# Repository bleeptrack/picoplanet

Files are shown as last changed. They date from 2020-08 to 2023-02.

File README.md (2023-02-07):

# PicoPlanet
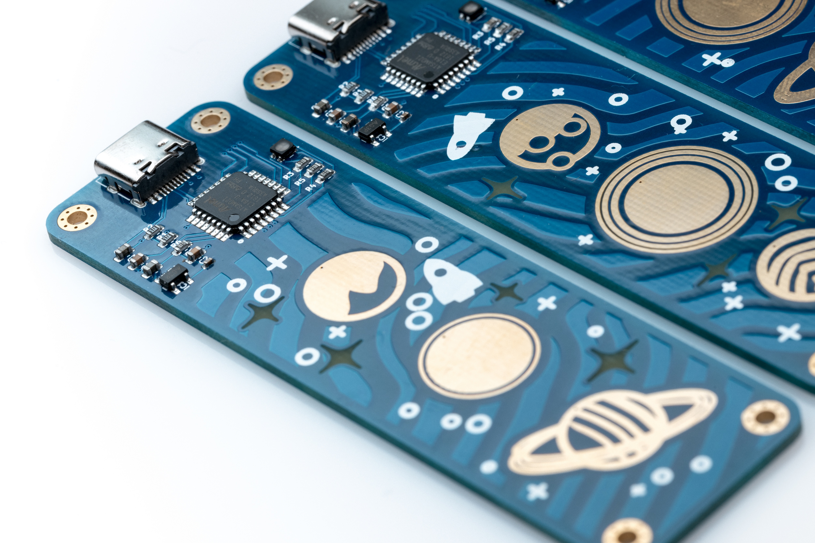
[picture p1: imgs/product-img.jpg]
Product Image

PicoPlanet is a series of procedurally designed PCBs.  
Available here: [Tindie](https://www.tindie.com/products/bleeptrack/picoplanet/)  
More information about the design process: link coming soon    

### Features:

- Dimensions: 27.0 x 89.2 mm

- SAMD21
- USB-C
- 3 capacitive touch buttons (planets)
- 1 RGB LED
- 4 additional pins on the backside with 3.3V and 5V

### Pinout
#### Front
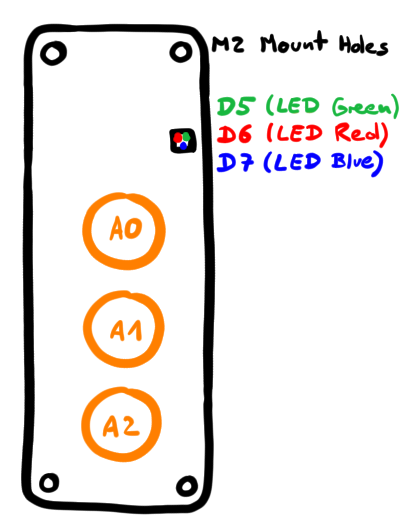
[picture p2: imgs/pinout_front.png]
Pinout Front

#### Back
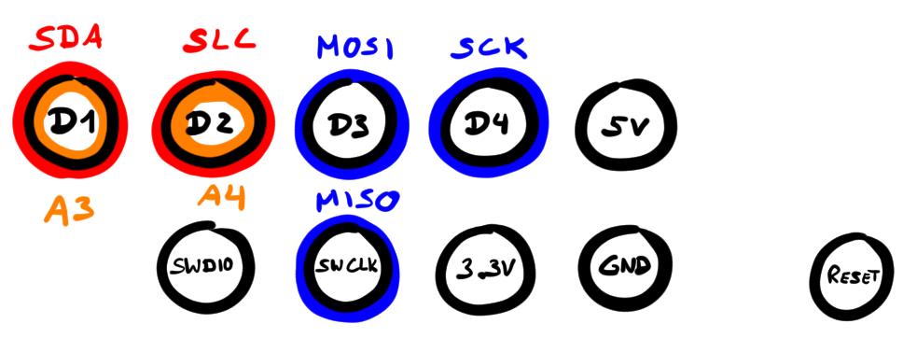
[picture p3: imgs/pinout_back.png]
Pinout Back


### Usage

Important: because the PCBs are procedurally generated, the threshold values for the capacitive touch buttons might need to be adjusted by you.

#### Circuit Python (recommended)

- Download Circuit Python from [circuitpython.org](https://circuitpython.org/board/picoplanet/)
- Connect your PicoPlanet to your PC. A drive called PLANETBOOT should appear.
- Place the firmware on the PLANETBOOT drive and wait for a moment. PLANETBOOT will dismount and a new drive called CIRCUITPY will appear. 
- More information on Circuit Python can be found here: [CPY getting started](https://learn.adafruit.com/welcome-to-circuitpython)
- In case you want to update your Circuit Python Version, you need to bring your board back to bootloader mode. This can be done by connecting a wire to the GND pin on the backside and double tap the RESET pad with the other end of the wire. The PLANETBOOT drive should appear now and you can place the updated firmware in the drive. See [example video](https://youtu.be/1Hi12uxtpS8). 

#### Arduino
- In your Arduino IDE, unter File > Preferences add `https://boards.bleeptrack.de/package_bleeptrack_index.json` to "Additional Boards Manager URLs"
- Open your Board Manager. Search for "bleeptrack boards" and install them.
- Choose bleeptrack boards > PicoPlanet in your Board selection
- Compile and upload :)
- If Arduino does not detect your PicoPlanet board, bring your board into bootloader mode by connecting a wire to the GND pin on the backside and double tap the RESET pad with the other end of the wire. The PLANETBOOT drive should appear now and the Arduino IDE will recognize the board again. See [example video](https://youtu.be/1Hi12uxtpS8). 
- The LED RGB Pins can directly be accessed by `LED_R`, `LED_G`, `LED_B`

#### Troubleshooting
- `bossac` not found when compiling Arduino Sketch: reinstall `bleeptrack-boards` package or install another package that contains bossac like `Arduino SAMD Boards (32-bits ARM Cortex-M0+)`

## Generator

You can play with the generator yourself. Run `npm install` in the `generator` folder to download the dependencies. Open `index.html` and reload the page to generate a new image. You have two options to save: `Perfect Purple` gives a SVG that is compatible with svg2shenzen and is made for typical PCBs (like the Oshpark's Perfect Purple). You can also choose `After Dark` which is specifically made for Oshpark's After Dark with a black base plate and a clear solder mask.

The generated images are currently not suitable to use them directly for pen plotters (and in the vector format also not for laser cutters). You might need to adjust them to your needs.

You are free to use the code and the generated images in any non-commercial way. 

## Accessories
- A case by [tinyledmatrix](https://twitter.com/tinyledmatrix) can be found in this repo in the ``frameCase`` folder
- Another case by Kartoffel is on Thingiverse: [Bumpercase](https://www.thingiverse.com/thing:4583005)

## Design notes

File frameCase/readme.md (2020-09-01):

Little 3D-printed case/frame for PicoPlanet by Alex (@tinyledmatrix)

Included Files:
STL
3MF with used settings in PrusaSlicer

License:
All files in this directory are
[CC-NC-SA-4.0](https://creativecommons.org/licenses/by-nc-sa/4.0/)

How does it look?
See [this](https://twitter.com/tinyledmatrix/status/1300056528297373696) Tweet

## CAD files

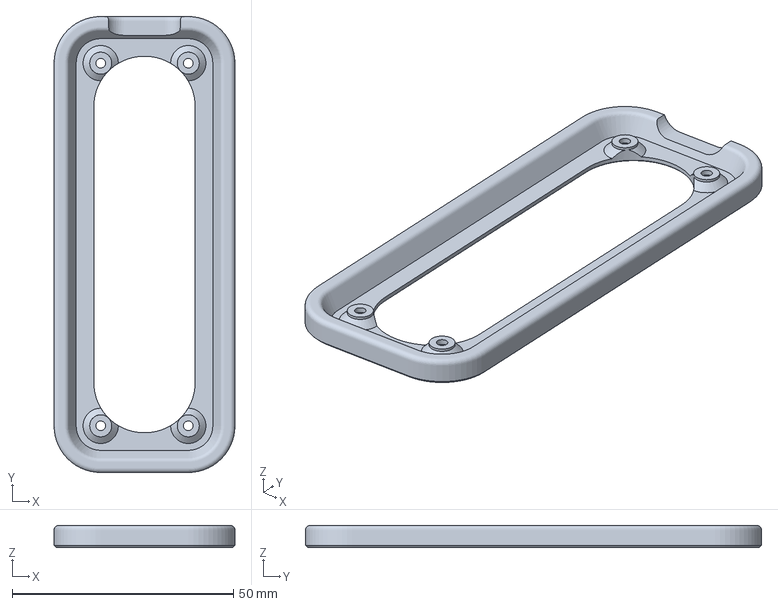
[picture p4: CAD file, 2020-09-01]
frameCase/picoPlanetFrame.3mf
40.9 x 103.2 x 5.00 mm

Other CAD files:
frameCase/picoPlanetFrame.stl

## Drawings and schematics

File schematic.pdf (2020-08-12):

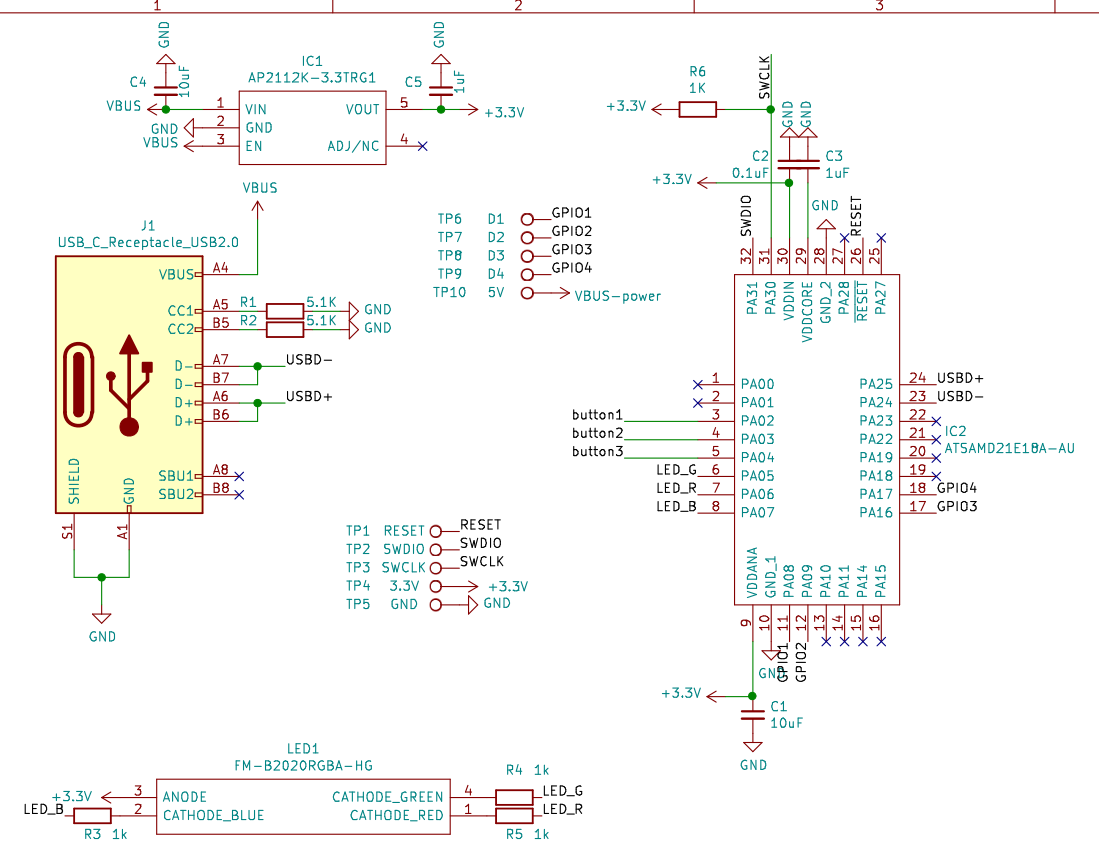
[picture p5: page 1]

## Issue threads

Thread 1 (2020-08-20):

Arduino: Upload Error: bossac not found

HayWo, 2020-08-20:
Uploading a sketch to the PicoPlanet fails, because a tool called `bossac` was not found.

### How to fix this
Install the Arduino Board Manager called `Arduino SAMD Boards (32-bits ARM Cortex-M0+)`

bleeptrack, 2020-08-20:
Hey HayWo! Oh well, that's weird! I tested on a fresh arduino install and did not encounter this problem. bossac is declared in the toolDependencies and should be installed with the bleeptrack-board package. Though seems it did not work for you.
I'll add your workaround to a Troubleshooting section.
Would you mind telling me what Arduino IDE version and OS you are running? Thanks!

HayWo, 2020-08-20:
I'm using Arduino IDE 1.8.13 on Arch Linux. Maybe I just have a messed up installation of the IDE.

Closed 2020-08-20.

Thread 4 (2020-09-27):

Updating CircuitPython version

bergold, 2020-09-27:
Is there an easy way to get into the bootloader again? So I can drag-n-drop a new uf2 file.

bleeptrack, 2020-09-27:
Hey bergold! Yes there is :)
To bring your board into bootloader mode, connect a wire to the GND pin on the backside and double tap the RESET pad with the other end of the wire. The PLANETBOOT drive should appear now.

I currently only wrote about this in the Arduino section. I'll update the readme file in the Circuit Python section, too :)

bergold, 2020-09-27:
Thanks for the quick reply! :)

Closed 2020-09-27.

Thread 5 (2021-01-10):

PlatformIO support / example

xsrf, 2021-01-10:
Hey,
do you have any experience with support for PlatformIO? PlatformIO requires a board definition and won't work out of the box, even if some supported boards already use the `SAMD21E18A`.
I kind of made it work by creating my own board variant based on the Adafruit Trinket M0 but I have no clue if it was done correctly. I may add a PR if I'm confident enough, but I'd be thankful for any additional advice ;)

xsrf, 2021-01-10:
Okay, I came up with a working example: https://github.com/xsrf/picoplanet/tree/platformio/example/platformio
I have slightly different pin definitions in [variant.cpp](https://github.com/xsrf/picoplanet/blob/platformio/example/platformio/variants/bleeptrack_picoplanet/variant.cpp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) and [variant.h](https://github.com/xsrf/picoplanet/blob/platformio/example/platformio/variants/bleeptrack_picoplanet/variant.h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) though.

Since I used the Trinket M0 as template, I kept `Serial1` using `SERCOM0` and used `SERCOM2` for `I2C`. Since `SERCOM0` and `SERCOM2` share the same pins they can be used interchangeably but of course both cannot be used at the same time.
However, this allows for `Serial1` with `TX`/`RX` on `D1`/`D2`.

Also, I think you got the PWM channels wrong for the LEDs.
Yours is
```cpp
  { PORTA,  5, PIO_SERCOM, (PIN_ATTR_DIGITAL|PIN_ATTR_PWM|PIN_ATTR_TIMER), ADC_Channel5, PWM1_CH0, TCC0_CH1, EXTERNAL_INT_5 },
  { PORTA,  6, PIO_SERCOM, (PIN_ATTR_DIGITAL|PIN_ATTR_PWM|PIN_ATTR_TIMER), ADC_Channel6, PWM1_CH1, TCC1_CH0, EXTERNAL_INT_6 },
  { PORTA,  7, PIO_SERCOM, (PIN_ATTR_DIGITAL|PIN_ATTR_PWM|PIN_ATTR_TIMER), ADC_Channel7, PWM1_CH2, TCC1_CH1, EXTERNAL_INT_7 },
```
But I think it should be
```cpp
  { PORTA,  5, PIO_DIGITAL, (PIN_ATTR_DIGITAL|PIN_ATTR_ANALOG|PIN_ATTR_PWM|PIN_ATTR_TIMER), ADC_Channel5, PWM0_CH1, TCC0_CH1, EXTERNAL_INT_5 },
  { PORTA,  6, PIO_DIGITAL, (PIN_ATTR_DIGITAL|PIN_ATTR_ANALOG|PIN_ATTR_PWM|PIN_ATTR_TIMER), ADC_Channel6, PWM1_CH0, TCC1_CH0, EXTERNAL_INT_6 },
  { PORTA,  7, PIO_DIGITAL, (PIN_ATTR_DIGITAL|PIN_ATTR_ANALOG|PIN_ATTR_PWM|PIN_ATTR_TIMER), ADC_Channel7, PWM1_CH1, TCC1_CH1, EXTERNAL_INT_7 },
```
At least `analogWrite()` works fine with my definition for all three LEDs (see examle code).
Does `analogWrite()` work for you in the ArduinoIDE for all three LEDs?

bleeptrack, 2021-01-10:
Hey, thanks so much for your help (and sorry for my late reply)! I did a quick test and you are right: PWM is not working with my definition. Thanks a lot for checking - I'm really new into defining own board definitions for Arduino and it seems I messed up here. I'll test your version tomorrow and change it so it get's updated for the Arduino IDE.
Also thanks a lot for making PicoPlanets compatible with platformIO! I never used it myself, so feel free to make a PR :)

xsrf, 2021-01-11:
Well, this stuff is really not well documented... PlatformIO and Arduino IDE share kind of the same board definition schemes, but I didn't know that when I started yesterday ;) This is why I first used the Adafruit Trinket M0 as template, because it is one of the Boards already supported by Platform IO that uses the same MCU ( https://platformio.org/boards?filter%5Bmcu%5D=SAMD21E18A ).
It was after that, that I learned you had to do kind of the same and only then I had a first look a your arduino board files.

I think that's kind of fortunate at the end, because if I had found your board files first, I'd just copied and used them and maybe wouldn't have found the issues.

I still have to adapt mine a little... e.g. I've chosen the blue LED to be the `LED_BUILTIN` one, you chose red ;)

Also, I used `#define LED_R`, you used `static const uint8_t LED_R` ... Do you know any cases where this makes a difference? I've also seen the Trinket one using some `const` as well, but it's inconsistent anyways. I guess it matters when you use it by reference 🤔

Regarding PlatformIO support: So far, my example comes together with the boards definition, since your board is not yet officially supported. But this makes the project kinda bulky.
I don't know (yet) what the official way is to get a board submitted into the PlatformIO registry, but maybe we could have a look.
At least, the example project should contain everything that is needed...

xsrf, 2021-01-11:
Oh btw., just in case you'll try it out, the HID example doesn't work for me (in my platformio example). I do get a HID Keyboard in the device manager but the Media-Keys just do nothing... Never used HID so far and haven't looked into that any further for now.

bleeptrack, 2021-01-11:
I did a quick check and with your pin definition, PWN works now \o/

> I think that's kind of fortunate at the end, because if I had found your board files first, I'd just copied and used them and maybe wouldn't have found the issues.

Tbh I'm very happy that you found these issues! I had quite some trouble getting the definitions to work, so it's great that another person now checks them :) Sorry for your extra work though!

> Also, I used `#define LED_R`, you used `static const uint8_t LED_R` ... Do you know any cases where this makes a difference? I've also seen the Trinket one using some `const` as well, but it's inconsistent anyways. I guess it matters when you use it by reference thinking

Not really sure what the difference is. I took most of my definition from another board, but I#m not sure which one it was.

> Regarding PlatformIO support: So far, my example comes together with the boards definition, since your board is not yet officially supported. But this makes the project kinda bulky.
> I don't know (yet) what the official way is to get a board submitted into the PlatformIO registry, but maybe we could have a look.
> At least, the example project should contain everything that is needed...

From what I found they want a feature request: https://platformio.org/boards which would just be a issue in the github repo. I guess if we would provide all necessary information, the board should be quick to add. From the code base I think that we can not just add it via PR. At least I did not find the spot where the variant files are.

> Oh btw., just in case you'll try it out, the HID example doesn't work for me (in my platformio example). I do get a HID Keyboard in the device manager but the Media-Keys just do nothing... Never used HID so far and haven't looked into that any further for now.

Hum, it might be because the HID library I use is not the standard one. I choose the one from NicoHood because it has MediaKeys implemented and the standard one does not :(

I'm a bit occupied in the next few days, but after that I will update the Arduino IDE definitions with your changes :) Again thank you very much for your help!

xsrf, 2021-01-24:
> Hum, it might be because the HID library I use is not the standard one. I choose the one from NicoHood because it has MediaKeys implemented and the standard one does not :(

I've used the [correct library](https://github.com/xsrf/picoplanet/blob/platformio/example/platformio/platformio.ini#L20), but the media keys don't work on my windows pc. However, with the picoplanet connected to my android phone, they just work fine. Regular keys also work on windows. Not sure what the deal is, but it proofs that HID in general works fine.

I've now just created a PR ;)

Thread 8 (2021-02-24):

I added more types of keyboard input examples to the circuitpython example

SHMAUS-Carter, 2021-02-24:
#7 circuitpython keyboard_text_example
I'm still relatively new to pushes and pulls hopefully I did it correctly.

Closed 2021-02-24.

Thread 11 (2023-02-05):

Proposal: Add information how to update Circuit Python version

Isolator70, 2023-02-05:
Some time ago I installed Circuit Python version version 6.3.0 on my Picoplanet board and I'd like to update to the latest and greatest version 7.3.3 now.
I suspect that it can be done by means of the reset contact, but I am not really sure if this right.

--> Would you be so kind to add this information?

bleeptrack, 2023-02-07:
Hey Isolator70! That is a great suggestion, thank you a lot! With the latest commit 794ce11  I added a bullet point to the CP section that contains a description and video on how to get back to bootloader mode to update the firmware :)

Closed 2023-02-07.

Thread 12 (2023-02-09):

Question: Can the disk space of the Circuit Python drive be extended?

Isolator70, 2023-02-09:
In Bootloader mode (while updating CircuitPython) I see plenty of space on my PicoPlanet board:

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

After reboot back in "CircuitPython" mode the space is quite limited:

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

Is this intended to be so or can the space be increased in case more complex code/ libs max out the disk space?

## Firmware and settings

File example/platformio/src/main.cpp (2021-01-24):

#include <Arduino.h>
#include "Adafruit_FreeTouch.h"
#include "HID-Project.h"
#include "Wire.h"
#include "SPI.h"

Adafruit_FreeTouch qt_1 = Adafruit_FreeTouch(A0, OVERSAMPLE_4, RESISTOR_20K, FREQ_MODE_NONE);
Adafruit_FreeTouch qt_2 = Adafruit_FreeTouch(A1, OVERSAMPLE_4, RESISTOR_20K, FREQ_MODE_NONE);
Adafruit_FreeTouch qt_3 = Adafruit_FreeTouch(A2, OVERSAMPLE_4, RESISTOR_20K, FREQ_MODE_NONE);

void ledsOff();
void flashLED(uint8_t led, uint16_t duration);
void pulseLED(uint8_t led);
void pulseWhite();
void testIO();
void testUart1();
void testI2C();
void testSPI();

void setup() {
  // HID
  Keyboard.begin();
  // Serial
  Serial.begin(9600);
  Serial.println("Start!");
  // Init and test LEDs
  ledsOff();
  flashLED(LED_R, 1e3);
  flashLED(LED_G, 1e3);
  flashLED(LED_B, 1e3);
  pulseLED(LED_R);
  pulseLED(LED_G);
  pulseLED(LED_B);
  pulseWhite();
  ledsOff();
  
  // Periperial Tests:
  //testUart1();
  //testI2C();
  //testIO();
  //testSPI();

  // Init Touch
  qt_1.begin();
  qt_2.begin();
  qt_3.begin();
}

void loop() {
  //meassure values at capacitive touch buttons
  int result1 = qt_1.measure();
  int result2 = qt_2.measure();
  int result3 = qt_3.measure();
  //check if button is pressed aka value is high enough
  //important: LEDs are active when LOW!
  if(result1 > 500){
    digitalWrite(LED_R, LOW);
    Keyboard.write(KEY_VOLUME_MUTE);
    Serial.println('R');
    delay(200);
  }else{
    digitalWrite(LED_R, HIGH);
  }

  if(result2 > 500){
    digitalWrite(LED_G, LOW);
    Keyboard.write(KEY_VOLUME_UP);
    Serial.println('G');
    delay(200);
  }else{
    digitalWrite(LED_G, HIGH);
  }

  if(result3 > 500){
    digitalWrite(LED_B, LOW);
    Keyboard.write(KEY_VOLUME_DOWN);
    Serial.println('B');
    delay(200);
  }else{
    digitalWrite(LED_B, HIGH);
  }

}

void ledsOff() {
  pinMode(LED_R, OUTPUT);
  pinMode(LED_G, OUTPUT);
  pinMode(LED_B, OUTPUT);
  digitalWrite(LED_R,HIGH);
  digitalWrite(LED_G,HIGH);
  digitalWrite(LED_B,HIGH); 
}

void flashLED(uint8_t led, uint16_t duration) {
  digitalWrite(LED_R,!(LED_R==led));
  digitalWrite(LED_G,!(LED_G==led));
  digitalWrite(LED_B,!(LED_B==led));
  delay(duration);
  ledsOff();
}

void pulseLED(uint8_t led) {
  ledsOff();
  for(uint8_t i=255; i>0; i--) {
    analogWrite(led, i);
    delay(2);
  }
  for(uint8_t i=0; i<255; i++) {
    analogWrite(led, i);
    delay(2);
  }
  ledsOff();
}

void pulseWhite() {
  ledsOff();
  for(uint8_t i=255; i>0; i--) {
    analogWrite(LED_R, i);
    analogWrite(LED_G, i);
    analogWrite(LED_B, i);
    delay(2);
  }
  for(uint8_t i=0; i<255; i++) {
    analogWrite(LED_R, i);
    analogWrite(LED_G, i);
    analogWrite(LED_B, i);
    delay(2);
  }
  ledsOff();
}

void testIO() {
  Serial.println("Probe D1-D4 and SWDIO, SWCLK with oscilloscope or piezo.");
  pinMode(D1,OUTPUT);
  pinMode(D2,OUTPUT);
  pinMode(D3,OUTPUT);
  pinMode(D4,OUTPUT);
  pinMode(SWDIO,OUTPUT);
  pinMode(SWCLK,OUTPUT);
  uint8_t i = 0;
  while(1) {
    i++;
    digitalWrite(D1,(i>>1)&1);
    digitalWrite(D2,(i>>2)&1);
    digitalWrite(D3,(i>>3)&1);
    digitalWrite(D4,(i>>4)&1);
    digitalWrite(SWDIO,(i>>5)&1);
    digitalWrite(SWCLK,(i>>6)&1);
    delay(1);
  }
}

void testUart1() {
  Serial1.begin(9600);
  while(1) {
    Serial.print("Connect D1 (TX) and D2 (RX) for loopback; Serial1 Bytes available: ");
    Serial.println(Serial1.available());
    Serial1.write("A");
    delay(1e3);
  }
}

void testI2C() {
  Wire.begin();
  Serial.println("Sending via I2C D1 (SDA) D2 (SCL)");
  while(1) {
    Serial.print(".");
    Wire.beginTransmission(4); // transmit to device #4
    Wire.write("beef");        // sends four bytes
    Wire.endTransmission();    // stop transmitting
    delay(1e2);
  }
}

void testSPI() {
  SPI.begin();
  uint8_t val1,cnt=0;
  SPISettings settings(4000000, MSBFIRST, SPI_MODE0);
  while(1) {
    SPI.beginTransaction(settings);
    val1 = SPI.transfer(0x42);
    SPI.endTransaction();
    if(cnt++ == 0) {
      Serial.print("Test SPI, connect MOSI (D3) and MISO (SWCLK) OR GND and MISO (SWCLK): ");
      Serial.print(val1, HEX);
      Serial.println(" ");
    }
    delay(2);
  }
}

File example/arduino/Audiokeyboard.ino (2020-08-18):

//Important! Adafruit Freetouch Library is needed for the capacitive
//touch buttons to work. Install via Library Manager!
//https://www.arduino.cc/reference/en/libraries/adafruit-freetouch-library/

// This Example uses the HID-Project Library for
// Media control. Uncomment marked lines if you have
// https://github.com/NicoHood/HID installed

#include "Adafruit_FreeTouch.h"
//#include "HID-Project.h" //uncomment if HID library installed. See top comment

//capacitive button init
Adafruit_FreeTouch qt_1 = Adafruit_FreeTouch(A0, OVERSAMPLE_4, RESISTOR_20K, FREQ_MODE_NONE);
Adafruit_FreeTouch qt_2 = Adafruit_FreeTouch(A1, OVERSAMPLE_4, RESISTOR_20K, FREQ_MODE_NONE);
Adafruit_FreeTouch qt_3 = Adafruit_FreeTouch(A2, OVERSAMPLE_4, RESISTOR_20K, FREQ_MODE_NONE);


void setup() {

  Serial.begin(9600);

  //Set LED lines as output so we can use them
  pinMode(LED_R, OUTPUT);
  pinMode(LED_G, OUTPUT);
  pinMode(LED_B, OUTPUT);

  //check if capacitive buttons are working
  if (! qt_1.begin())
    Serial.println("Failed to begin qt on pin A0");
  if (! qt_2.begin())
    Serial.println("Failed to begin qt on pin A0");
  if (! qt_3.begin())
    Serial.println("Failed to begin qt on pin A0");

  //Keyboard.begin(); //uncomment if HID library installed. See top comment
}

void loop() {

  //meassure values at capacitive touch buttons
  int result1 = qt_1.measure();
  int result2 = qt_2.measure();
  int result3 = qt_3.measure();


  //check if button is pressed aka value is high enough
  //important: LEDs are active when LOW!
  if(result1 > 500){
    digitalWrite(LED_R, LOW);
    //Keyboard.write(KEY_VOLUME_MUTE); //uncomment if HID library installed. See top comment
    delay(200);
  }else{
    digitalWrite(LED_R, HIGH);
  }

  if(result2 > 500){
    digitalWrite(LED_G, LOW);
    //Keyboard.write(KEY_VOLUME_UP);   //uncomment if HID library installed. See top comment
    delay(200);
  }else{
    digitalWrite(LED_G, HIGH);
  }

  if(result3 > 500){
    digitalWrite(LED_B, LOW);
    //Keyboard.write(KEY_VOLUME_DOWN);   //uncomment if HID library installed. See top comment
    delay(200);
  }else{
    digitalWrite(LED_B, HIGH);
  }

}

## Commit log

2020-08-12 PicoPlanet Schematic
2020-08-30 Added files for 3D-printed case
    [picoPlanetFrame.3mf, picoPlanetFrame.stl]
2021-01-10 add platformio example with board variant
    [trinket_m0.cfg]
2021-01-12 used "static const" for pins and red LED as default
